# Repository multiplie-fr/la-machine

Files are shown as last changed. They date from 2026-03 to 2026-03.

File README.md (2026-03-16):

# la-machine

la machine revisits the legendary "Ultimate Machine"

This repository contains :
- the step files to print it yourself
- the schematics and the gerber files to manufacture the PCBA
- an example of a Micro Python code

For the original Erlang software, everything is on Paul's repository [here](https://github.com/pguyot/la_machine).

la machine is available for order at : [la-machine.fr](https://la-machine.fr)

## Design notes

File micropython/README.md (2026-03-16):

# Flashing MicroPython on ESP32-C3 with Thonny / Flasher MicroPython sur l'ESP32-C3 avec Thonny

---

## 1. Install Thonny / Installer Thonny

- Download Thonny from https://thonny.org
- Install it normally (Windows, macOS or Linux)

---

- Télécharger Thonny sur https://thonny.org
- L'installer normalement (Windows, macOS ou Linux)

## 2. Prepare Thonny / Préparer Thonny

The La Machine board already runs Erlang/AtomVM firmware. The board does have BOOT and RESET buttons, but they are inside the enclosure — you would need to disassemble the machine to reach them. To avoid that, we'll use a quicker method: **switch S3** (the main button on top of the box, the one that normally triggers the arm) wakes the ESP32-C3 from deep sleep, which briefly makes the USB serial port visible. It disappears as soon as the movement is finished and the ESP32-C3 goes back to deep sleep. You need to be quick!

La carte La Machine contient déjà le firmware Erlang/AtomVM. La carte possède bien des boutons BOOT et RESET, mais ils sont à l'intérieur du boîtier — il faudrait démonter la machine pour y accéder. Pour éviter ça, on va utiliser une méthode plus rapide : **l'interrupteur S3** (le bouton principal sur le dessus de la boîte, celui qui déclenche normalement le bras) réveille l'ESP32-C3 du deep sleep, ce qui rend le port série USB brièvement visible. Il disparaît dès que le mouvement est terminé et que l'ESP32-C3 retourne en deep sleep. Il faut être rapide !

1. Plug the La Machine board via USB / Brancher la carte La Machine en USB
2. Open Thonny / Ouvrir Thonny
3. Go to **Tools > Options > Interpreter** / Aller dans **Outils > Options > Interpréteur**
4. Select **MicroPython (ESP32)** as interpreter / Sélectionner **MicroPython (ESP32)** comme interpréteur
5. Click **Install or update MicroPython (esptool)** / Cliquer sur **Installer ou mettre à jour MicroPython (esptool)**
6. In the install window, pre-configure everything **before** waking the machine:
   - **MicroPython family**: ESP32
   - **Variant**: Espressif ESP32-C3
   - Leave the latest version selected
   - Leave **Target port** for now

   Dans la fenêtre d'installation, pré-configurer tout **avant** de réveiller la machine :
   - **MicroPython family** : ESP32
   - **Variant** : Espressif ESP32-C3
   - Laisser la version la plus récente
   - Laisser **Target port** pour l'instant

## 3. Flash MicroPython (the tricky part!) / Flasher MicroPython (la partie délicate !)

This is a race against the clock: the serial port only stays active for a few seconds while the Erlang firmware runs a movement.

C'est une course contre la montre : le port série ne reste actif que quelques secondes pendant que le firmware Erlang exécute un mouvement.

1. **Get ready**: have the Thonny install window open with everything pre-configured (see step 2 above)
2. **Press the main button (S3)** on top of the box to wake up the machine
3. **Immediately** click the refresh button next to **Target port** — the serial port should appear (e.g. `/dev/cu.usbmodem...` on macOS, `COM3` on Windows)
4. **Select the port** and **click Install** as fast as possible
5. If the flash starts, you're good — `esptool` takes control of the ESP32 and the deep sleep timer no longer matters
6. Wait for flashing to complete (a few minutes)
7. Close the install window

---

1. **Se préparer** : avoir la fenêtre d'installation de Thonny ouverte avec tout pré-configuré (voir étape 2 ci-dessus)
2. **Actionner l'interrupteur S3** sur la boîte pour réveiller la machine
3. **Immédiatement** cliquer sur le bouton rafraîchir à côté de **Target port** — le port série devrait apparaître (ex : `/dev/cu.usbmodem...` sur macOS, `COM3` sur Windows)
4. **Sélectionner le port** et **cliquer Installer** le plus vite possible
5. Si le flashage démarre, c'est gagné — `esptool` prend le contrôle de l'ESP32 et le timer de deep sleep n'a plus d'effet
6. Attendre la fin du flashage (quelques minutes)
7. Fermer la fenêtre d'installation

> **Tip / Astuce**: If you miss the window, just press the main button (S3) again to wake the machine and retry. It may take a few attempts!
> Si vous ratez la fenêtre, appuyez à nouveau sur le bouton principal (S3) pour réveiller la machine et réessayez. Il faudra peut-être plusieurs tentatives !

## 4. Verify it works / Vérifier que ça fonctionne

1. Unplug and replug the USB cable / Débrancher et rebrancher le câble USB
2. In Thonny, the shell at the bottom should display / Dans Thonny, le shell en bas devrait afficher :

```
MicroPython v1.xx.x on xxxx-xx-xx; ESP32C3 module with ESP32C3
>>>
```

3. Type `print("hello")` in the shell to verify / Taper `print("hello")` dans le shell pour vérifier

> Now that MicroPython is flashed, the serial port stays active permanently (no more deep sleep race condition!).
> Maintenant que MicroPython est flashé, le port série reste actif en permanence (plus besoin de course contre la montre !).

## 5. Upload project files / Transférer les fichiers du projet

1. In Thonny, open `main.py` (**File > Open**, navigate to the `la-machine-DIY` folder)
2. Go to **File > Save as...**
3. Choose **MicroPython device** as destination
4. Name the file `main.py` (this name matters: MicroPython runs it automatically at startup)
5. Do the same for the sound file `sound.wav`:
   - In the **Files** panel in Thonny (**View > Files** if not visible)
   - Navigate to `sound.wav` on your computer (top panel)
   - Right-click `sound.wav` > **Upload to /**

> The WAV file must be: **16-bit, mono, 44100 Hz**. To convert an existing file, use Audacity or the command:
> ```
> ffmpeg -i my_sound.mp3 -ar 44100 -ac 1 -sample_fmt s16 sound.wav
> ```

---

1. Dans Thonny, ouvrir le fichier `main.py` (menu **Fichier > Ouvrir**, naviguer jusqu'au dossier `la-machine-DIY`)
2. Faire **Fichier > Enregistrer sous...**
3. Choisir **Périphérique MicroPython** comme destination
4. Nommer le fichier `main.py` (ce nom est important : MicroPython l'exécute automatiquement au démarrage)
5. Faire la même chose pour le fichier son `sound.wav` :
   - Dans le panneau **Fichiers** de Thonny (menu **Affichage > Fichiers** si pas visible)
   - Naviguer jusqu'au fichier `sound.wav` sur l'ordinateur (panneau du haut)
   - Clic droit sur `sound.wav` > **Transférer vers le périphérique**

> Le fichier WAV doit être : **16 bits, mono, 44100 Hz**. Pour convertir un fichier existant, utiliser Audacity ou la commande :
> ```
> ffmpeg -i mon_son.mp3 -ar 44100 -ac 1 -sample_fmt s16 sound.wav
> ```

## 6. Run the program / Lancer le programme

- Unplug and replug the USB cable (or click the Stop/Restart button in Thonny)
- `main.py` runs automatically at boot
- In Thonny, the shell displays `La Machine DIY - starting` then `Ready - waiting for button press...`
- Flip switch S3 to trigger the machine

---

- Débrancher et rebrancher le câble USB (ou cliquer sur le bouton Stop/Redémarrer dans Thonny)
- Le programme `main.py` se lance automatiquement au démarrage
- Dans Thonny, le shell affiche `La Machine DIY - starting` puis `Ready - waiting for button press...`
- Actionner l'interrupteur S3 pour déclencher la machine

## 7. Troubleshooting / Dépannage

| Problem / Problème | Solution |
|---|---|
| Serial port not detected / Port série non détecté | Install the USB driver (CH340 or CP2102 depending on the board). On macOS, try another USB cable (some are charge-only). / Installer le driver USB (CH340 ou CP2102 selon la carte). Sur macOS, essayer un autre câble USB (certains ne font que la charge). |
| `PWM is inactive` | Make sure you have the latest version of `main.py`. / Vérifier que vous avez la dernière version du `main.py`. |
| No sound / Pas de son | Check that `sound.wav` is on the device (Files panel). Check the format (16-bit mono 44100Hz). / Vérifier que `sound.wav` est bien sur le périphérique (panneau Fichiers). Vérifier le format (16-bit mono 44100Hz). |
| `ENOMEM` / Out of memory | The WAV file is too large for the filesystem. Shorten the sound or lower the sample rate to 22050Hz (and update `I2S_SAMPLE_RATE` in `main.py`). / Le fichier WAV est trop gros. Réduire la durée du son ou baisser le sample rate à 22050Hz (et modifier `I2S_SAMPLE_RATE` dans `main.py`). |
| Servo doesn't move / Le servo ne bouge pas | Check that the battery is charged (the boost circuit needs it). / Vérifier que la batterie est chargée (le boost circuit en a besoin). |

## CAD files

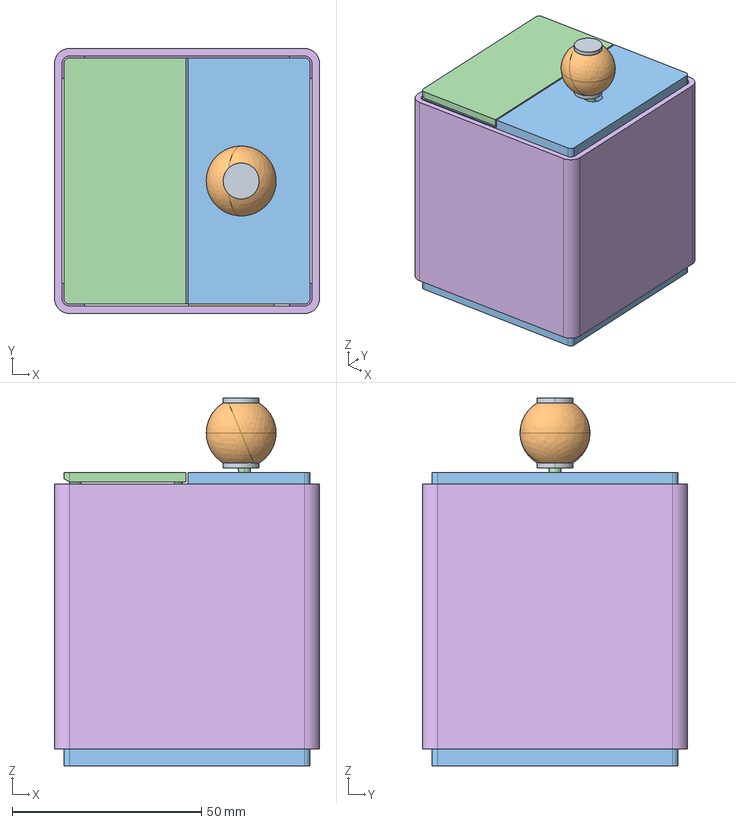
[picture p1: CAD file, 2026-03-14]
mechanical/la-machine.stp
70.0 x 70.0 x 97.2 mm

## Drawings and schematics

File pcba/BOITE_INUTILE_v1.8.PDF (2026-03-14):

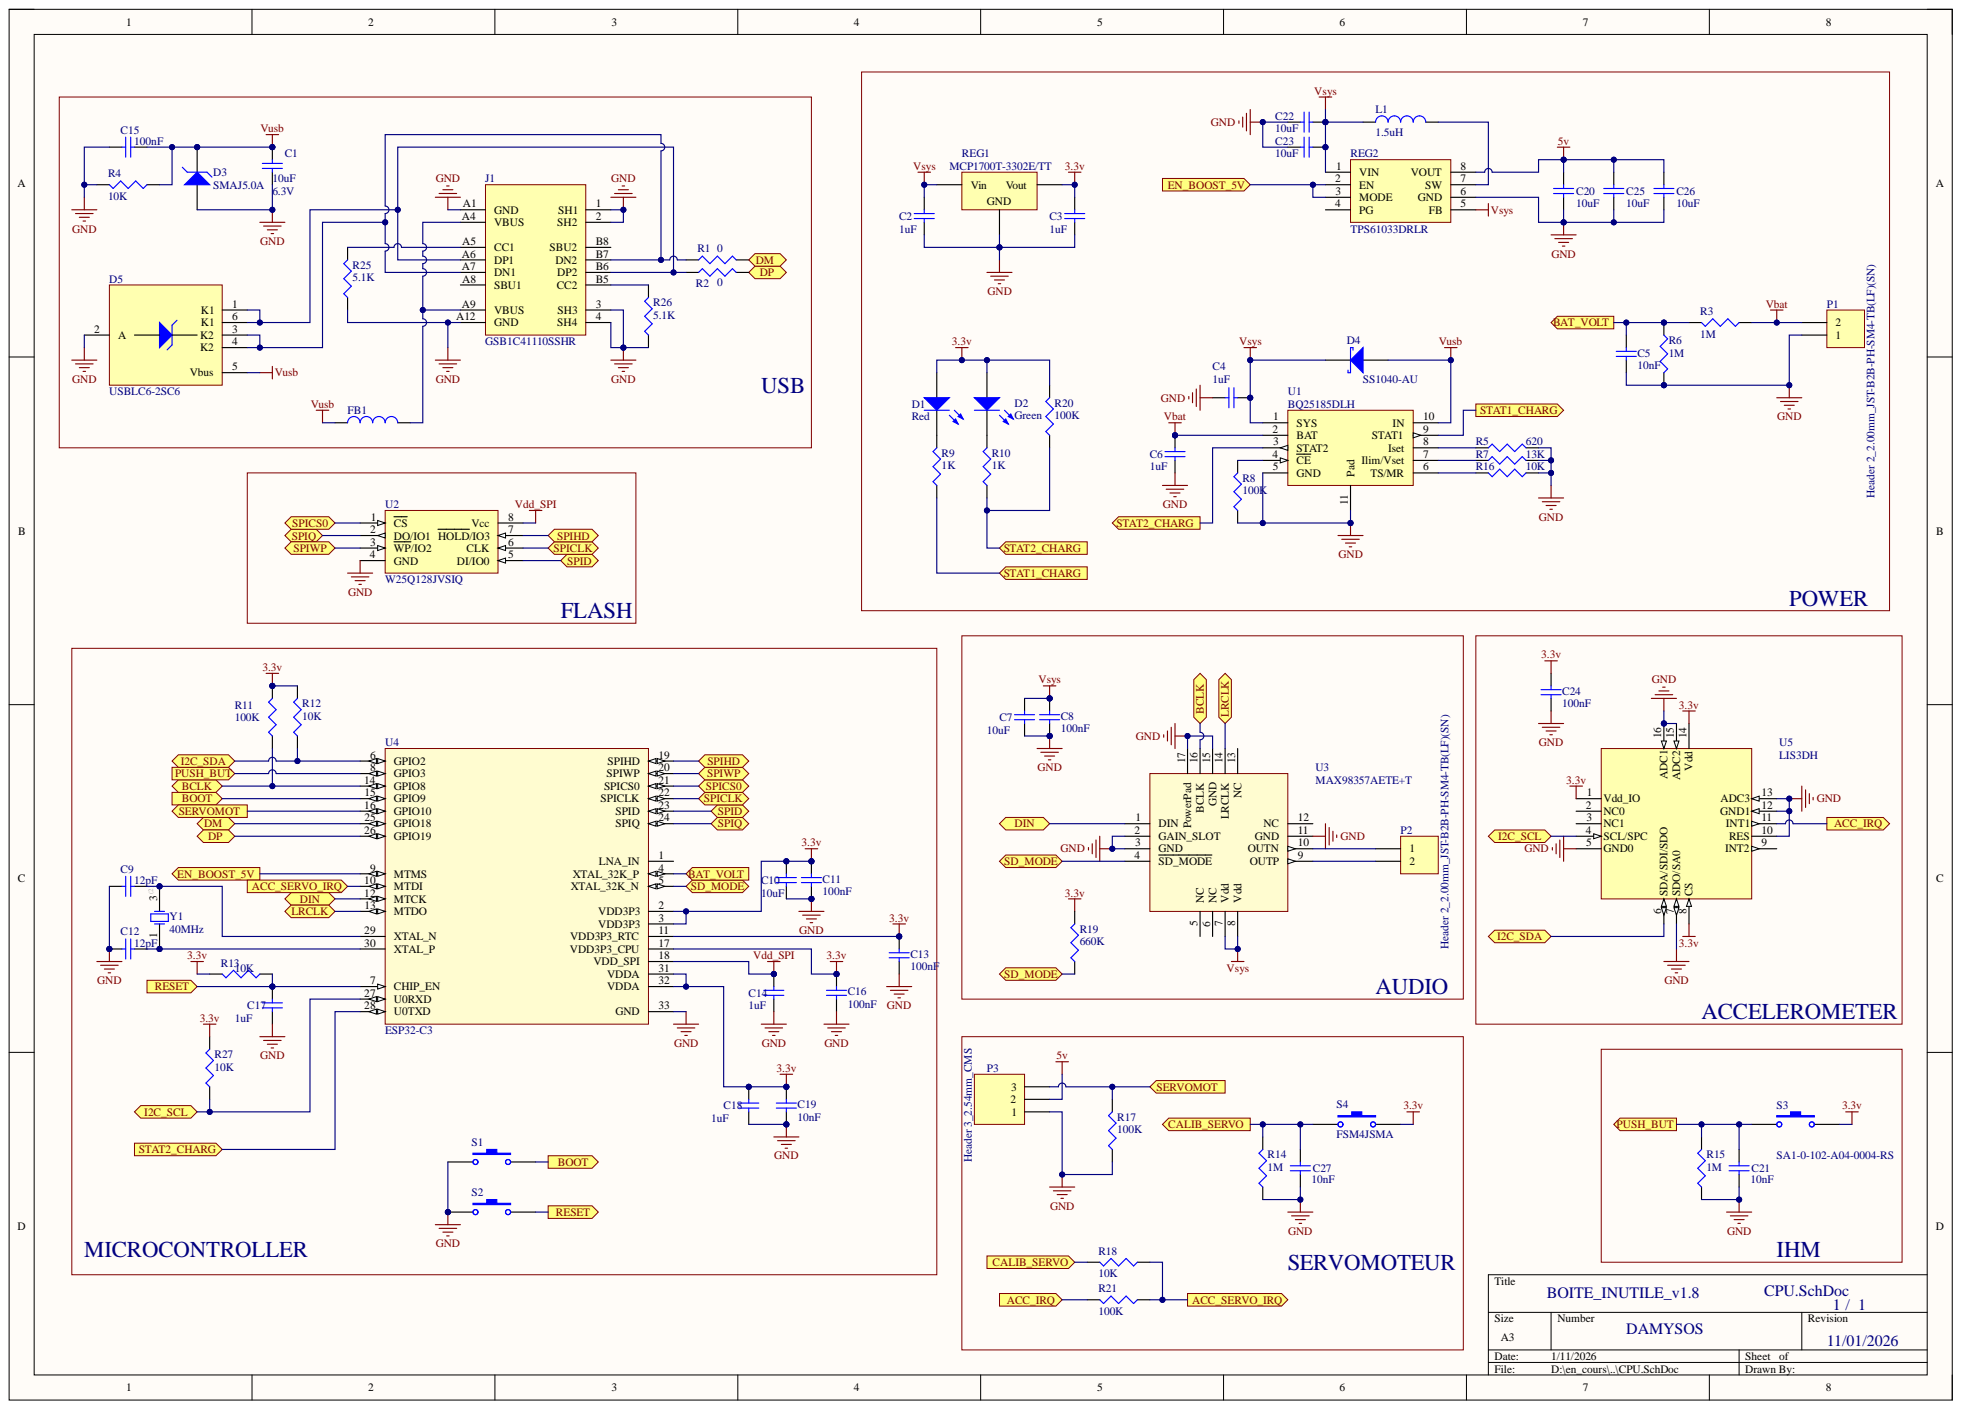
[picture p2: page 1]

GND J1 GND

VIN 1 GND FB | 5 PG 4 6 MODE 3

Header 2_2.00mm_JST-B2B-PH-SM4-TB(LF)(SN)

U0TXD 28 U0RXD 27 | C14

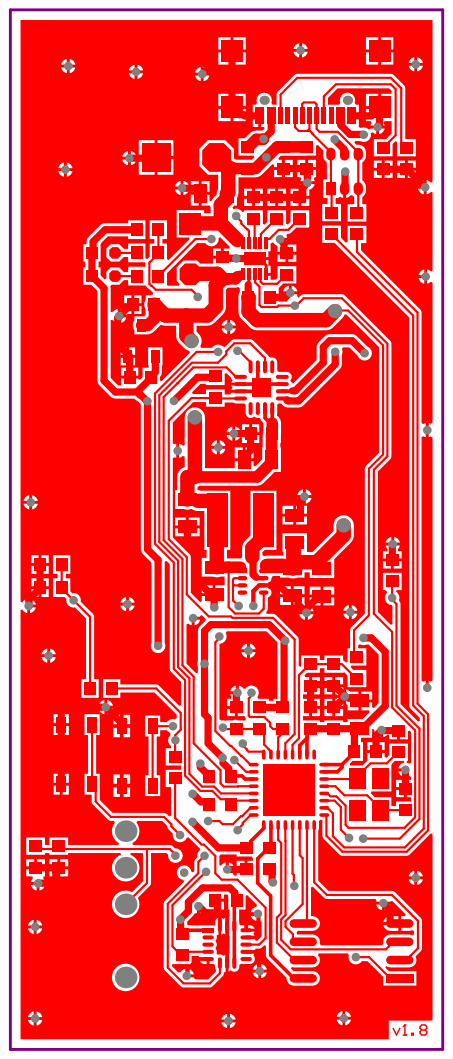
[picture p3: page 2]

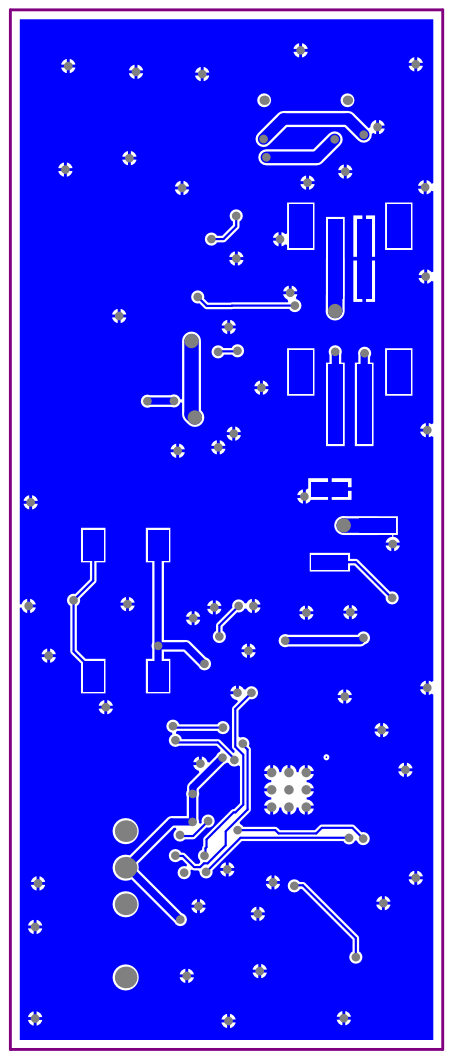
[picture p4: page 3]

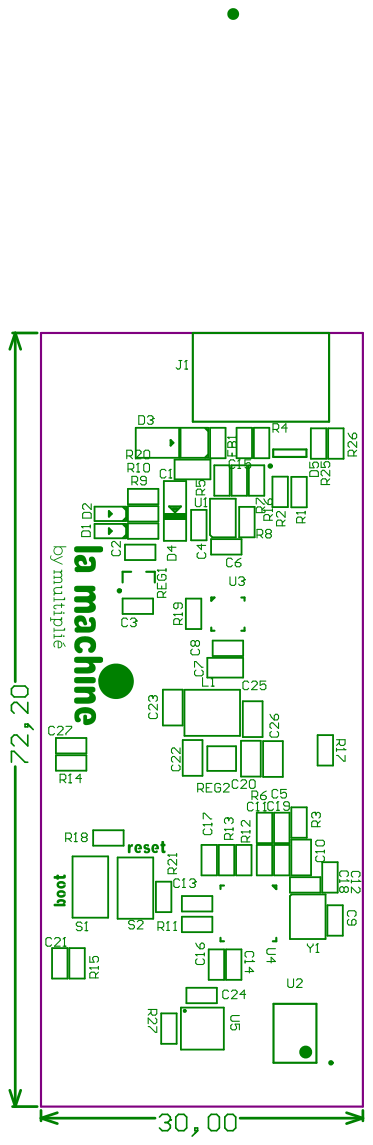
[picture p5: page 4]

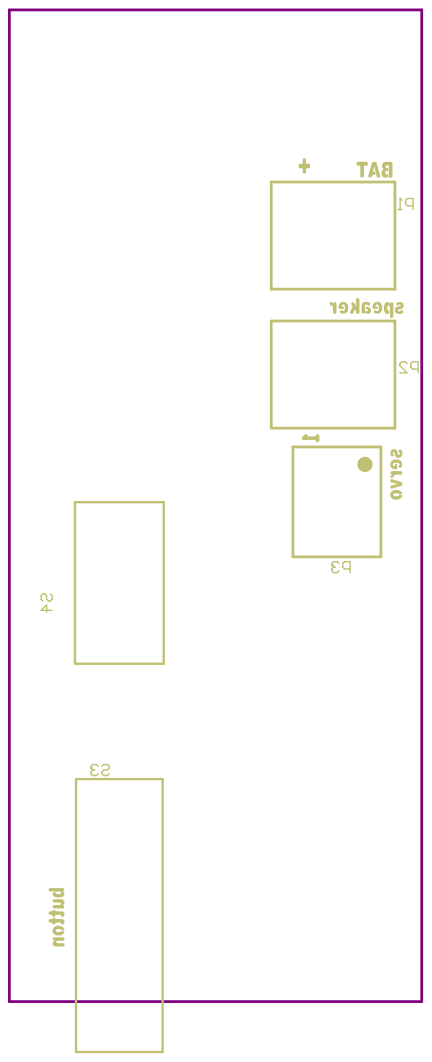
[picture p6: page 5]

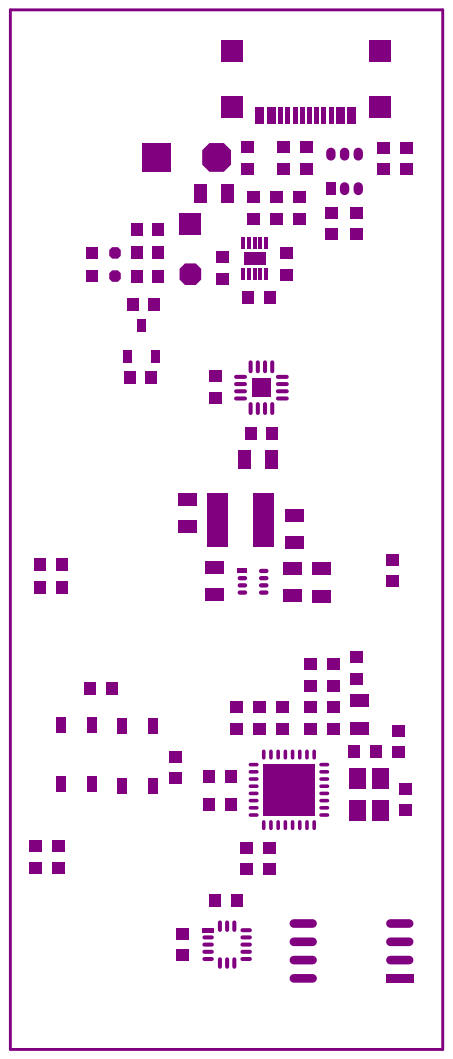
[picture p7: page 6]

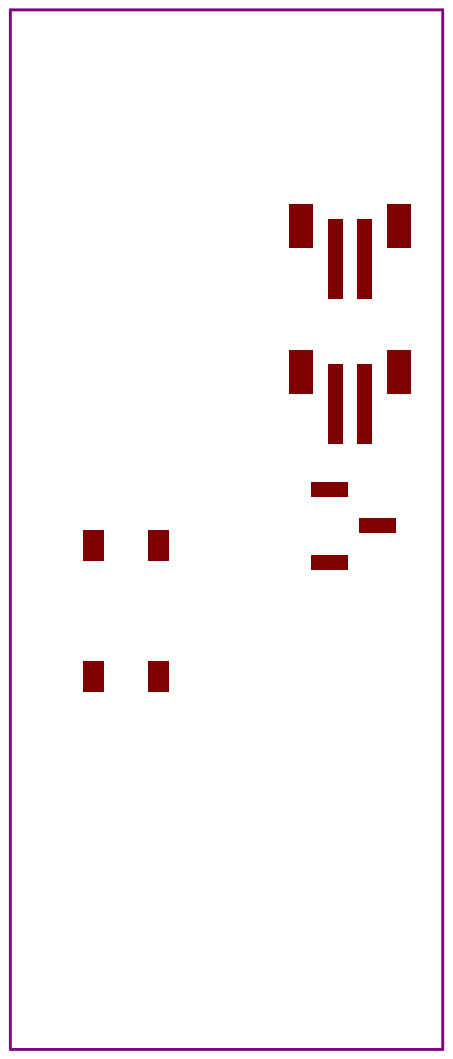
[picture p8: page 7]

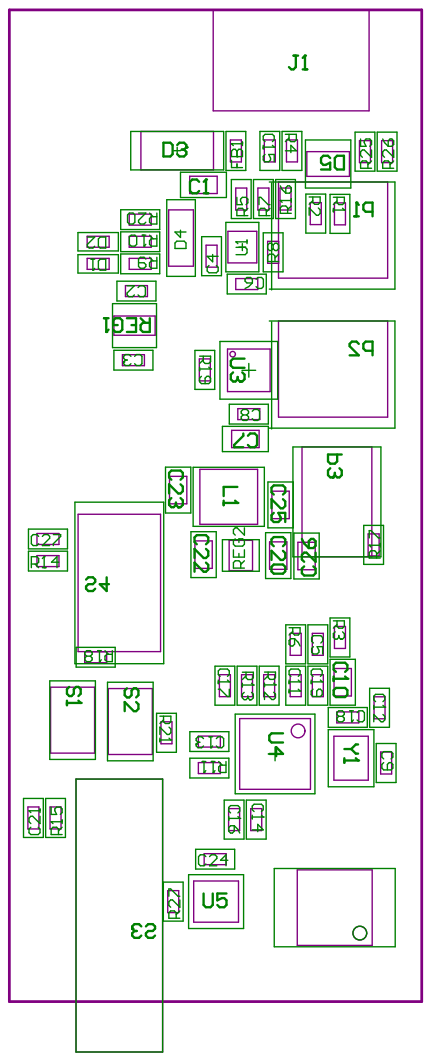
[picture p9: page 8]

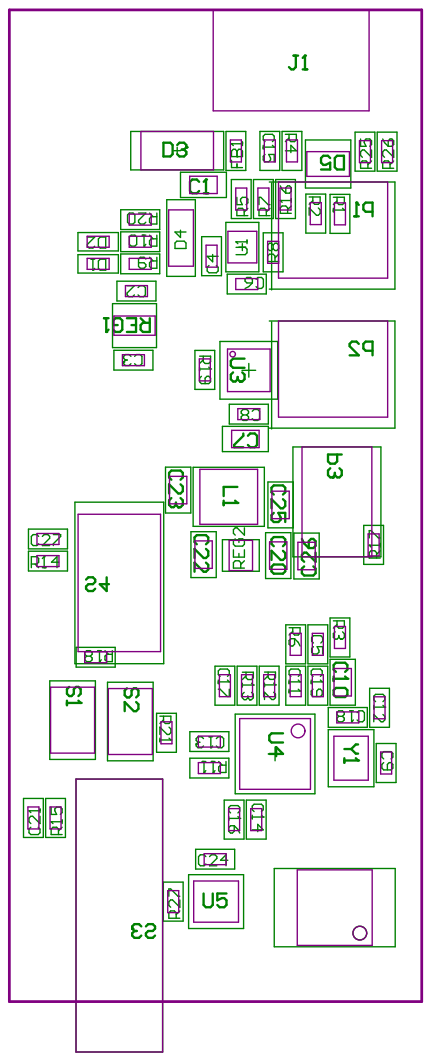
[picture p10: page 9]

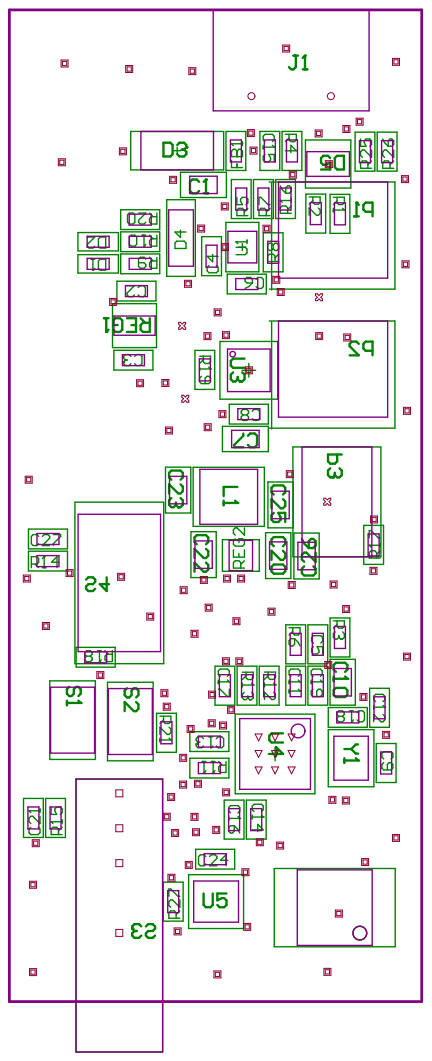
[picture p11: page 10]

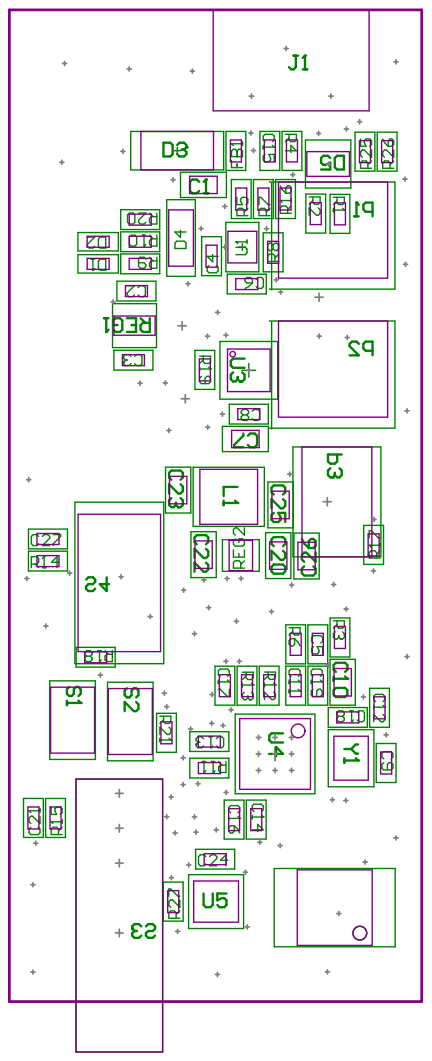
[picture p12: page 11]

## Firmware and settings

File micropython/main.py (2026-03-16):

"""
La Machine DIY - MicroPython for ESP32-C3
Waits for switch S3, then moves the servo arm while playing a sound.
"""

import machine
import time
from machine import Pin, PWM, I2S

# --- Pin definitions (from La Machine PCBA v1.8) ---
BUTTON_PIN = 3          # Switch S3, active high
SERVO_PWM_PIN = 10      # Servo signal
SERVO_BOOST_PIN = 4     # Servo boost enable (powers the servo)
AMP_SD_MODE_PIN = 1     # MAX98357A amplifier enable (high = on)
I2S_BCLK_PIN = 8        # I2S bit clock
I2S_LRC_PIN = 7         # I2S word select / LR clock
I2S_DIN_PIN = 6         # I2S data out to amplifier

# --- Servo parameters ---
SERVO_FREQ = 50         # 50 Hz standard servo
# Pulse widths in nanoseconds (from the Erlang calibration)
SERVO_CLOSED_NS = 1_889_000   # ~1889us - lid closed
SERVO_OPEN_NS = 833_000       # ~833us  - lid open (arm out)
SERVO_MOVE_TIME_MS = 800      # Time to allow for servo movement

# --- Audio parameters ---
AUDIO_FILE = "sound.wav"       # Place a 16-bit mono WAV file (44100 or 48000 Hz) on the filesystem
I2S_SAMPLE_RATE = 44100
I2S_BITS = 16
I2S_BUF_SIZE = 4096


def setup_button():
    """Configure the button pin with pull-down (switch pulls high when activated)."""
    return Pin(BUTTON_PIN, Pin.IN, Pin.PULL_DOWN)


def setup_servo():
    """Configure servo PWM at 50Hz, initially in closed position."""
    pwm = PWM(Pin(SERVO_PWM_PIN), freq=SERVO_FREQ, duty_u16=0)
    pwm.duty_ns(SERVO_CLOSED_NS)
    return pwm


def setup_servo_boost():
    """Servo boost enable pin - controls power to the servo."""
    boost = Pin(SERVO_BOOST_PIN, Pin.OUT)
    boost.value(0)  # Off initially
    return boost


def setup_amp():
    """MAX98357A amplifier SD_MODE pin - high to enable."""
    amp = Pin(AMP_SD_MODE_PIN, Pin.OUT)
    amp.value(0)  # Off initially
    return amp


def setup_i2s():
    """Configure I2S output for audio playback."""
    audio_out = I2S(
        0,
        sck=Pin(I2S_BCLK_PIN),
        ws=Pin(I2S_LRC_PIN),
        sd=Pin(I2S_DIN_PIN),
        mode=I2S.TX,
        bits=I2S_BITS,
        format=I2S.MONO,
        rate=I2S_SAMPLE_RATE,
        ibuf=I2S_BUF_SIZE,
    )
    return audio_out


def servo_move(pwm, duty_ns):
    """Move servo to a position specified by pulse width in nanoseconds."""
    pwm.duty_ns(duty_ns)


def play_sound(audio_out, amp):
    """Play WAV file through I2S. Skips the 44-byte WAV header."""
    try:
        f = open(AUDIO_FILE, "rb")
    except OSError:
        print("Sound file '{}' not found - skipping audio".format(AUDIO_FILE))
        return

    amp.value(1)  # Enable amplifier
    time.sleep_ms(10)  # Let amp stabilize

    # Skip WAV header (standard 44 bytes)
    f.read(44)

    buf = bytearray(I2S_BUF_SIZE)
    while True:
        n = f.readinto(buf)
        if n is None or n == 0:
            break
        audio_out.write(buf[:n])

    f.close()
    time.sleep_ms(50)  # Let last samples play out
    amp.value(0)  # Disable amplifier


def run_action(servo, boost, audio_out, amp):
    """The main action: open lid (move servo) while playing sound, then close."""
    # Power on servo
    boost.value(1)
    time.sleep_ms(20)

    # Move servo to open position
    servo_move(servo, SERVO_OPEN_NS)

    # Play sound (blocking - servo stays open during playback)
    play_sound(audio_out, amp)

    # Wait a bit with lid open if sound was short
    time.sleep_ms(200)

    # Close lid
    servo_move(servo, SERVO_CLOSED_NS)
    time.sleep_ms(SERVO_MOVE_TIME_MS)

    # Power off servo
    boost.value(0)


def main():
    print("La Machine DIY - starting")

    button = setup_button()
    servo = setup_servo()
    boost = setup_servo_boost()
    amp = setup_amp()
    audio_out = setup_i2s()

    print("Ready - waiting for button press...")

    button_was_pressed = False

    while True:
        if button.value() == 1:
            if not button_was_pressed:
                button_was_pressed = True
                print("Button pressed! Running action...")
                run_action(servo, boost, audio_out, amp)
                print("Action complete. Waiting for next press...")
        else:
            button_was_pressed = False

        time.sleep_ms(20)  # Debounce / polling interval


main()
